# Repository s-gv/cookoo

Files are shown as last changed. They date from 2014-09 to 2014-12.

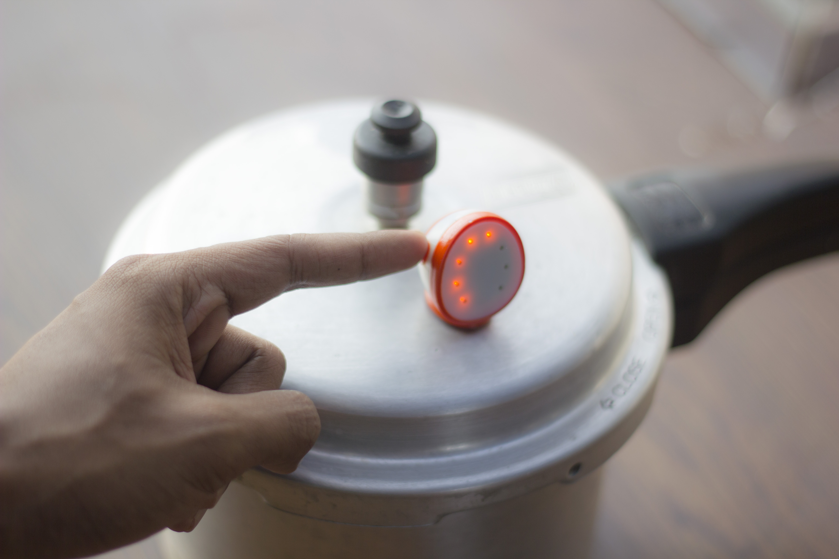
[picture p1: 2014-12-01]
images/_MG_3987.jpg

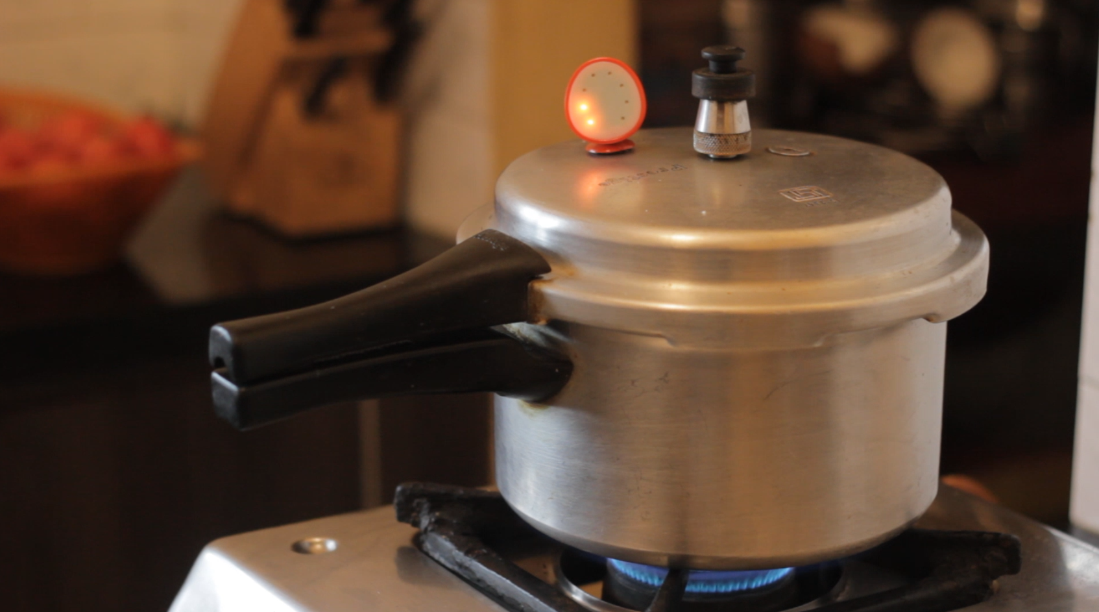
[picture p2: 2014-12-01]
images/whistle1.png

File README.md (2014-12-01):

cookoo
======

Cookoo is a pressure cooker whistle counter. Keep it on your cooker and forget about it. Cookoo will tell you when to turn off the stove.

Dependencies
------------

- MSPGCC and GNU Make (only if you want to re-build)
- Flash Programmer (TI Launchpad will do)
- Flash Programmer Tool (TI Code Composer Studio / FET-Pro430 / TI MSP430 Flasher/ mspdebug)

On Ubuntu 12.04, the dependencies can be installed with `sudo apt-get install binutils-msp430 gcc-msp430 msp430-libc mspdebug`

How-to-use
----------

- Build the circuit in the [schematic](schematic/whistle_counter.png) and program the MSP430 with the [hex file](bin/msp430cookoo.hex)
- [Gerber files](pcb/gerber) for the PCB are available along with images to [assist manual assembly](pcb/)
- The [STL files](enclosure/) may be used to 3D-print an enclosure

Notes
-----

- Pour hot glue over the crystal pins, the 22pF caps, and all over the MSP430 pins to prevent moisture from interfering with the low-power 32kHz crystal oscillator
- The [PCB design](pcb/) included has a minor inconvenience. For the wire-terminated thermistor, SMD0402 pads have been provided (rather than two through-holes)
- The contact area with the cooker should be at least 1cm x 1cm for efficient heat transfer. To do this, paste the thermistor on the backside of a thin copper sheet.

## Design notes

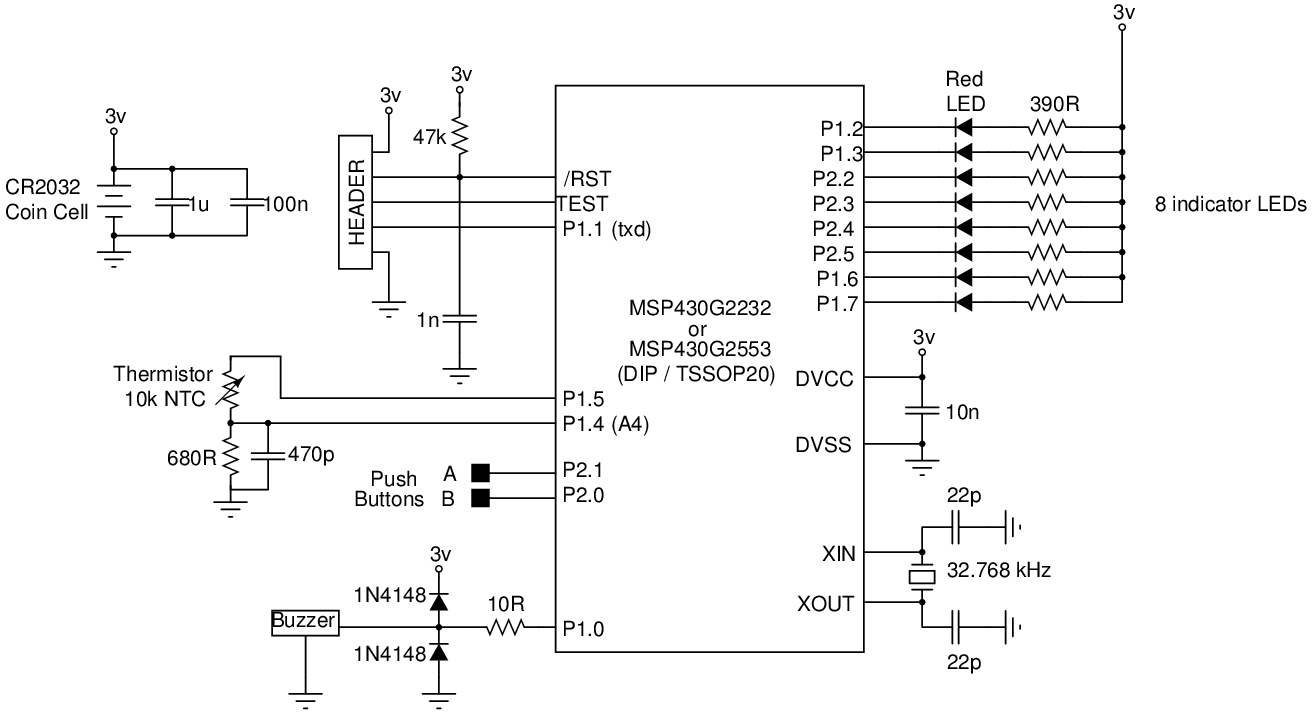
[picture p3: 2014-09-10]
schematic/whistle_counter.png

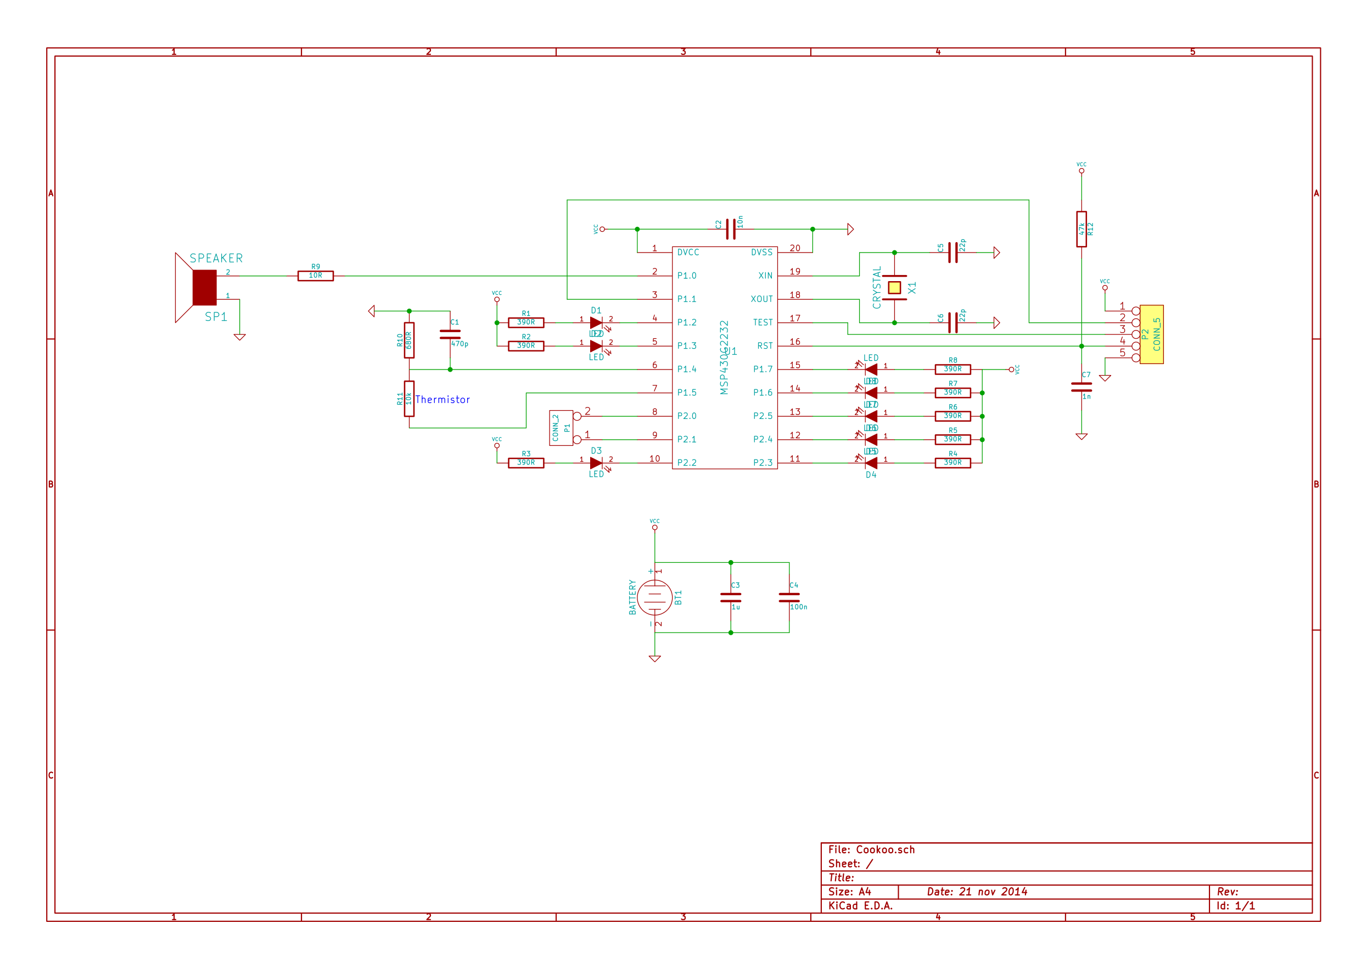
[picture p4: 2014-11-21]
pcb/pcb_schematic.png

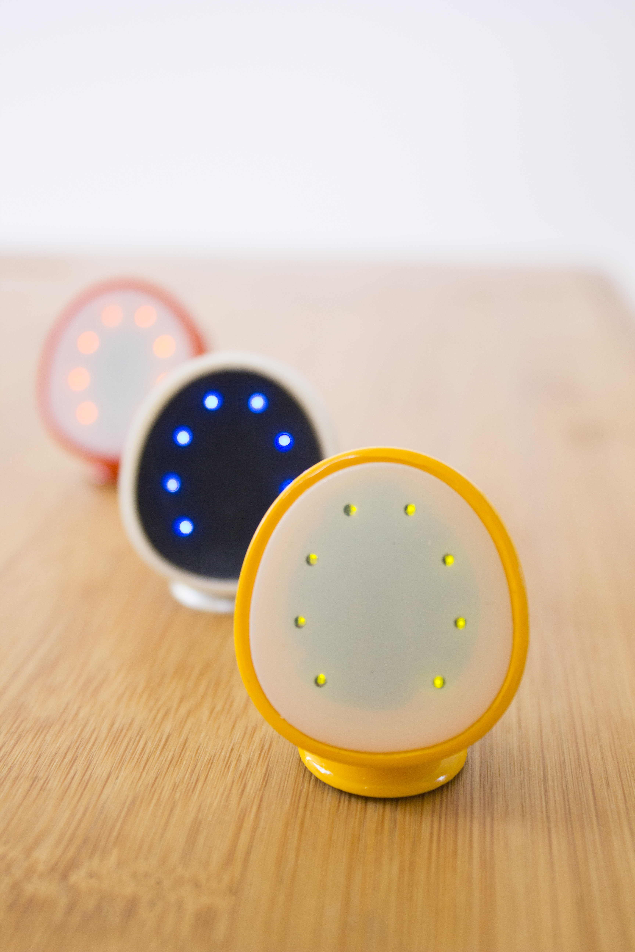
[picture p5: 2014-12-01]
images/_MG_3925.jpg

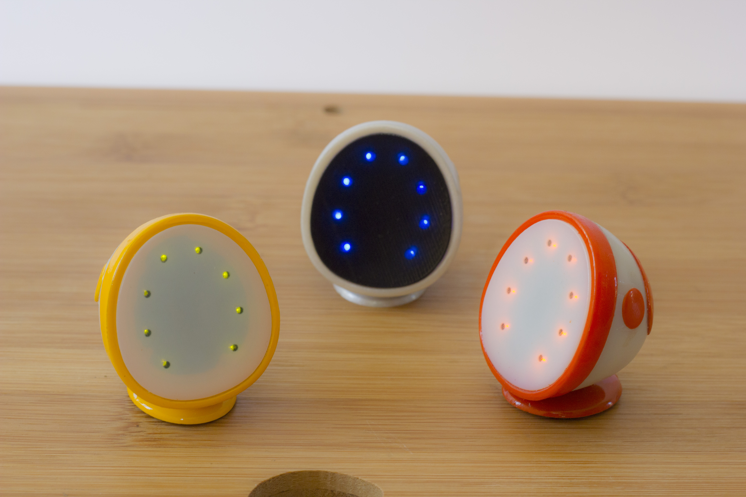
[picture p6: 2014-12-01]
images/_MG_3888.jpg

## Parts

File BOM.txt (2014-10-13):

Quantity x Part Number
======================

1x MSP430G2232 (TSSOP 20 pin)

1x CR2032 Coin cell battery and battery holder

1x Buzzer (through hole, continuous > 80 dB indicator buzzer)

1x 32.768 kHz Crystal (through hole)

2x 1N4148 diode (through hole)

8x Red LED (SMD 0402)

1x 10k 1/16 W NTC Thermistor (Wire terminated, Upto 150 degree Celcius)

1x 10R, 1/16 W (SMD 0402)
8x 390R, 1/16 W (SMD 0402)
1x 680R, 1/16 W (SMD 0402)
1x 47k, 1/16 W (SMD 0402)

2x 22pF, 5V (SMD 0402, Ceramic)
1x 470pF, 5V (SMD 0402, Ceramic)
1x 1nF, 5V (SMD 0402, Ceramic)
1x 10nF, 5V (SMD 0402, Ceramic)
1x 100nF, 5V (SMD 0402, Ceramic)
1x 1uF, 5V (SMD 0402, Ceramic)

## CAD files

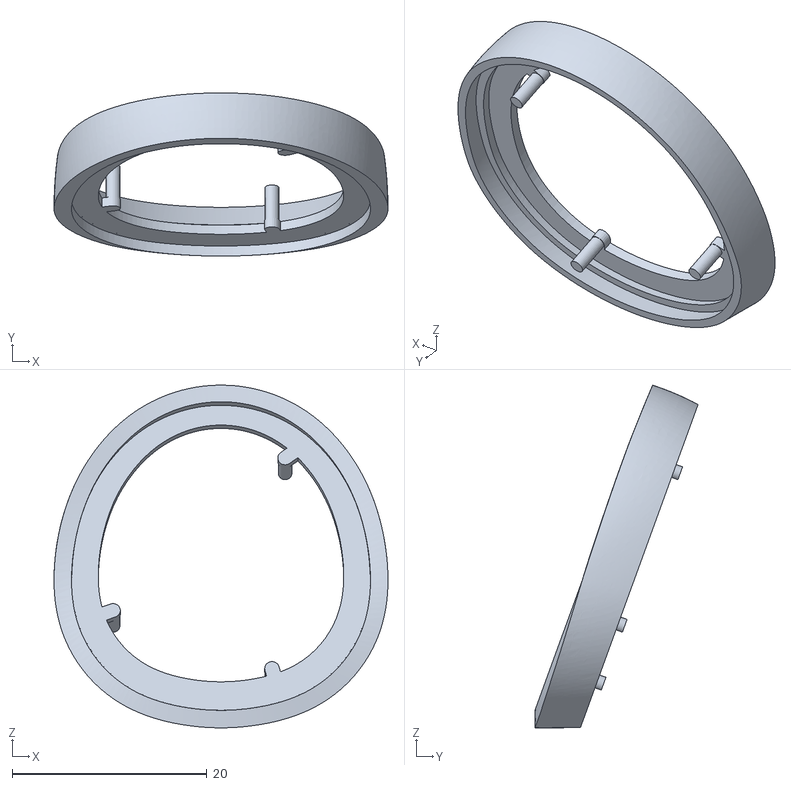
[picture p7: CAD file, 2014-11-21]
enclosure/Front.stl
34.3 x 16.8 x 35.2

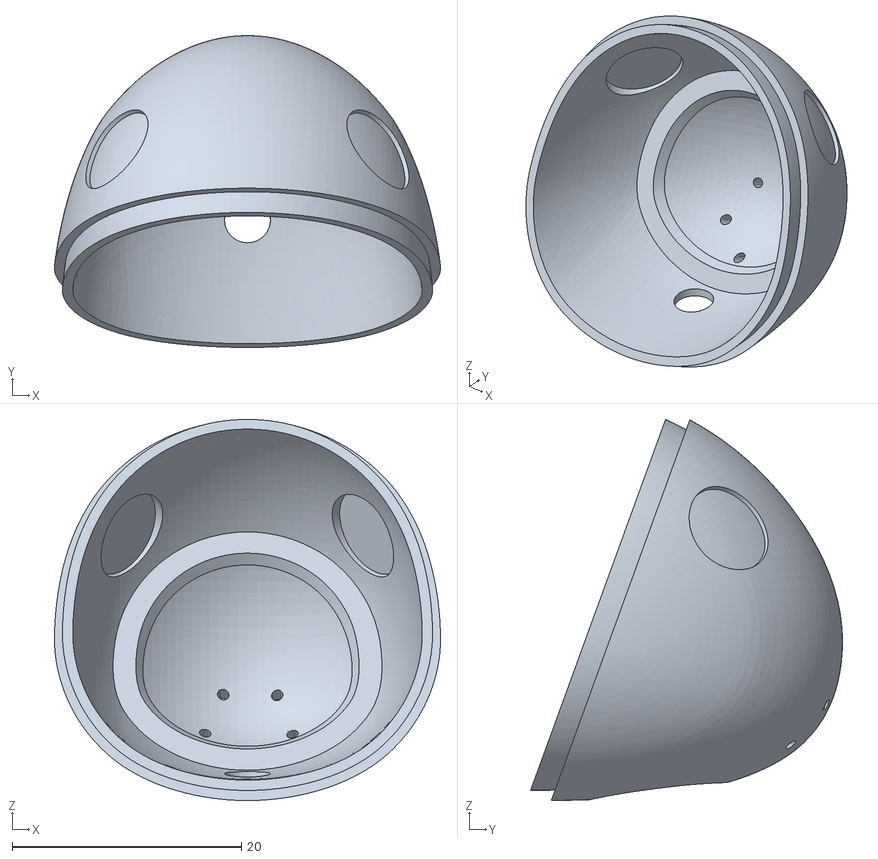
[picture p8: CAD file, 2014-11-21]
enclosure/Rear.stl
33.6 x 27.2 x 33.2

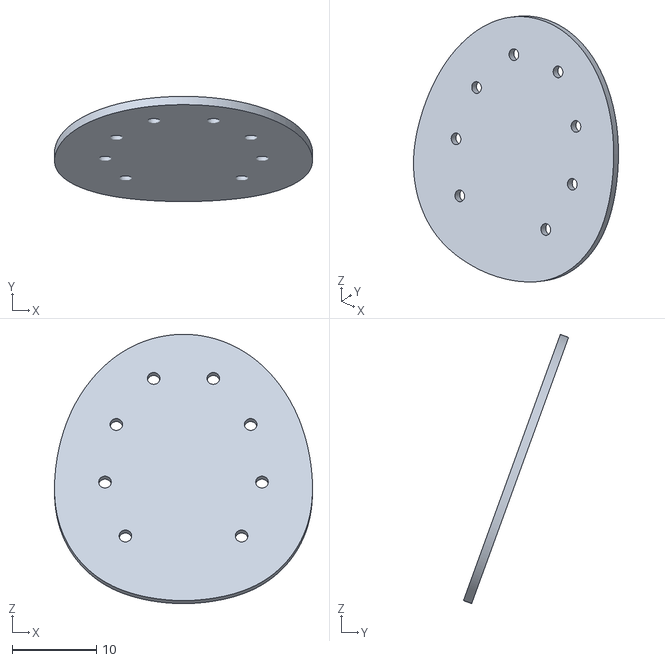
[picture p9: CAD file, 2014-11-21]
enclosure/Panel.stl
30.7 x 12.5 x 32.0

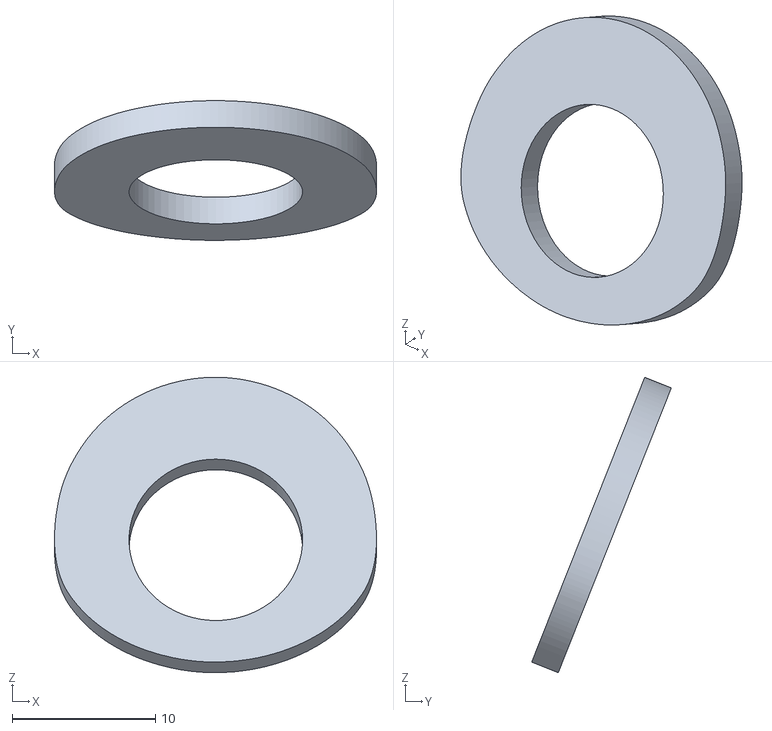
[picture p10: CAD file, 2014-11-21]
enclosure/buzzerPlate.stl
22.4 x 9.74 x 20.6

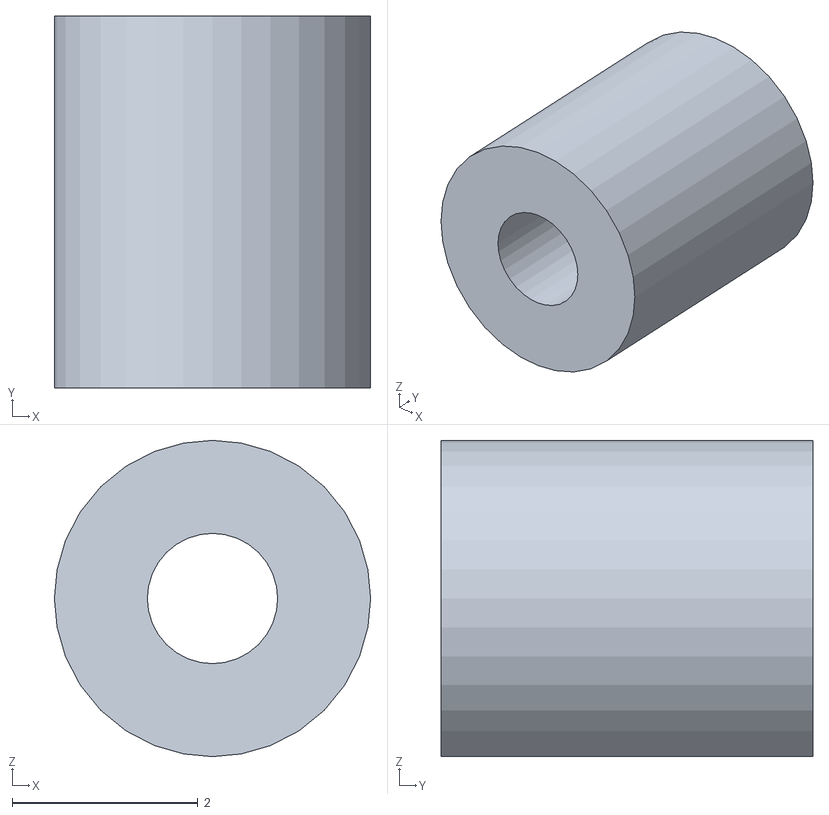
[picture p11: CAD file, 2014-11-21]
enclosure/Plug.stl
3.40 x 4.00 x 3.40

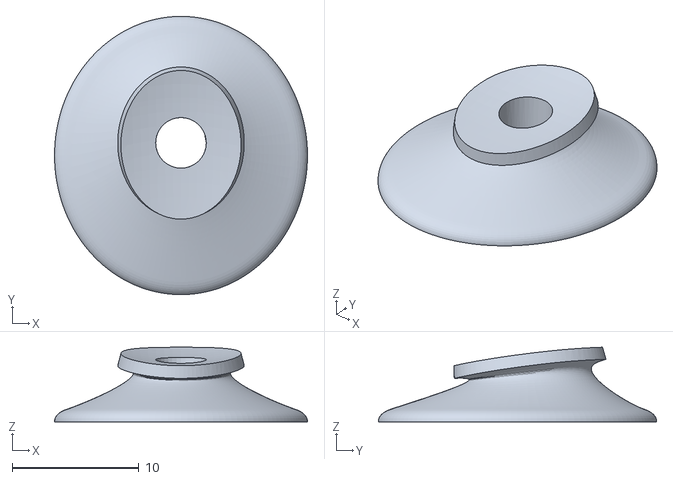
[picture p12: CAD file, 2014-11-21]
enclosure/stand.stl
20.0 x 22.0 x 5.90

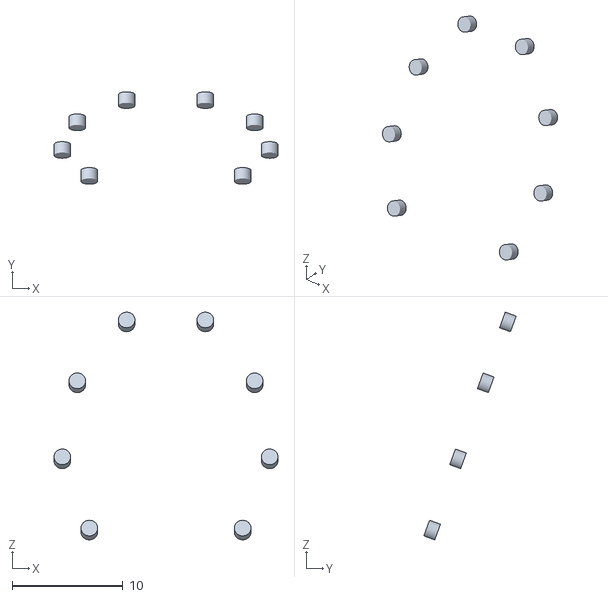
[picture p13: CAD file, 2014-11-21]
enclosure/leds.stl
20.2 x 8.33 x 20.5

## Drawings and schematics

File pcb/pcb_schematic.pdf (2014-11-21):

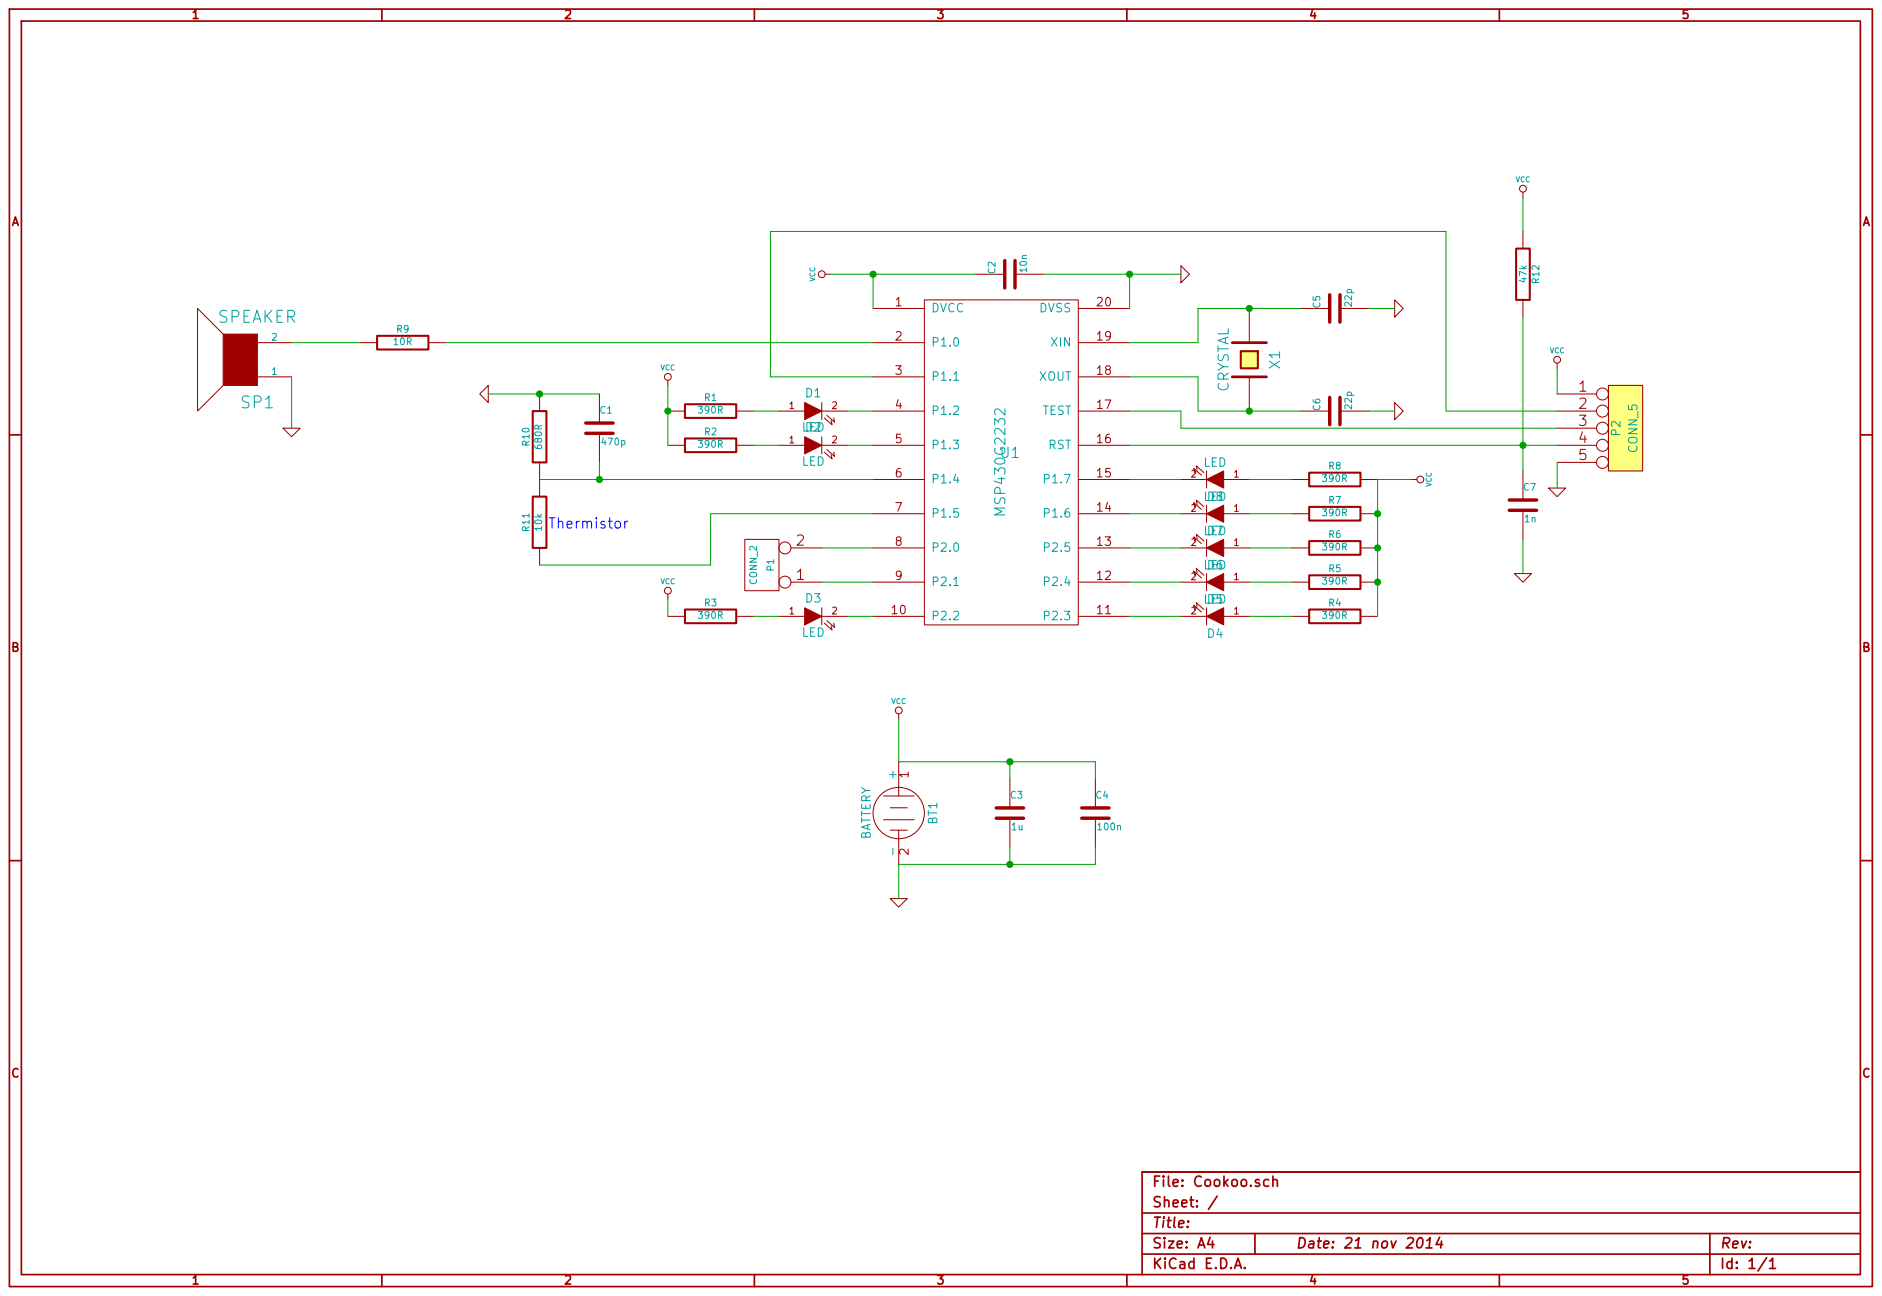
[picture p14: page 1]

-2 BT1 BATTERY DVCC 1 P1.0 2 P1.1 3 P1.2 4 P1.3 5 P1.4 6 P1.5 7 P2.0 8 P2.1 9 P2.2 10 DVSS 20 P2.3 11 P2.4 12 P2.5 13 P1.6 14 P1.7 15 RST 16 TEST 17 XOUT 18 XIN 19 U1MSP430G2232 C522p C622p

Id: 1/1 Title: File: Cookoo.sch

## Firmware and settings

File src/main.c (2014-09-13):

/*
Copyright (c) 2014, Sagar G V (sagar.writeme@gmail.com) and Dhruv Saxena (dhruvrai23@gmail.com)
All rights reserved.

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
* Neither the names of the copyright holders nor the names of its
  contributors may be used to endorse or promote products derived from
  this software without specific prior written permission.

THIS SOFTWARE IS PROVIDED BY THE COPYRIGHT HOLDERS AND CONTRIBUTORS "AS IS"
AND ANY EXPRESS OR IMPLIED WARRANTIES, INCLUDING, BUT NOT LIMITED TO, THE
IMPLIED WARRANTIES OF MERCHANTABILITY AND FITNESS FOR A PARTICULAR PURPOSE ARE
DISCLAIMED. IN NO EVENT SHALL THE COPYRIGHT HOLDER OR CONTRIBUTORS BE LIABLE
FOR ANY DIRECT, INDIRECT, INCIDENTAL, SPECIAL, EXEMPLARY, OR CONSEQUENTIAL
DAMAGES (INCLUDING, BUT NOT LIMITED TO, PROCUREMENT OF SUBSTITUTE GOODS OR
SERVICES; LOSS OF USE, DATA, OR PROFITS; OR BUSINESS INTERRUPTION) HOWEVER
CAUSED AND ON ANY THEORY OF LIABILITY, WHETHER IN CONTRACT, STRICT LIABILITY,
OR TORT (INCLUDING NEGLIGENCE OR OTHERWISE) ARISING IN ANY WAY OUT OF THE USE
OF THIS SOFTWARE, EVEN IF ADVISED OF THE POSSIBILITY OF SUCH DAMAGE.
*/

#include <msp430.h>
#include <inttypes.h>

#include "cappush.h"
#include "cookoo.h"
#include "uart.h"
#include "hal.h"

int main(void) {
    uint16_t tempSensor, battery;
    uint8_t capPushA, capPushB;
    uint8_t it=1;

    InitWDT();
    InitCLOCK();
    InitUART();
    InitLED();
    InitADC();
    InitBuzzer();
    InitCapPush();
    
    EnableInterrupts();
    while (1) {
        it--;
        if(it == 0) {
            it = 4;
            capPushA = senseCapPushA(); 
            capPushB = senseCapPushB(); 
            tempSensor = ReadTemp();
            battery = ReadBattery(); 
            MainLoop(capPushA, capPushB, tempSensor, battery);
        }
        SetupWDTToWakeUpCPU(2); // Wake up in 16 mS
        Sleep();
    }
    return 0;
}

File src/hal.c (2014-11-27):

/*
Copyright (c) 2014, Sagar G V (sagar.writeme@gmail.com) and Dhruv Saxena (dhruvrai23@gmail.com)
All rights reserved.

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
* Neither the names of the copyright holders nor the names of its
  contributors may be used to endorse or promote products derived from
  this software without specific prior written permission.

THIS SOFTWARE IS PROVIDED BY THE COPYRIGHT HOLDERS AND CONTRIBUTORS "AS IS"
AND ANY EXPRESS OR IMPLIED WARRANTIES, INCLUDING, BUT NOT LIMITED TO, THE
IMPLIED WARRANTIES OF MERCHANTABILITY AND FITNESS FOR A PARTICULAR PURPOSE ARE
DISCLAIMED. IN NO EVENT SHALL THE COPYRIGHT HOLDER OR CONTRIBUTORS BE LIABLE
FOR ANY DIRECT, INDIRECT, INCIDENTAL, SPECIAL, EXEMPLARY, OR CONSEQUENTIAL
DAMAGES (INCLUDING, BUT NOT LIMITED TO, PROCUREMENT OF SUBSTITUTE GOODS OR
SERVICES; LOSS OF USE, DATA, OR PROFITS; OR BUSINESS INTERRUPTION) HOWEVER
CAUSED AND ON ANY THEORY OF LIABILITY, WHETHER IN CONTRACT, STRICT LIABILITY,
OR TORT (INCLUDING NEGLIGENCE OR OTHERWISE) ARISING IN ANY WAY OUT OF THE USE
OF THIS SOFTWARE, EVEN IF ADVISED OF THE POSSIBILITY OF SUCH DAMAGE.
*/

#include "hal.h"

static void __attribute__((__interrupt__(WDT_VECTOR))) WDT_ISR(void) {
    LPM3_EXIT; // Return to active mode
}

static void __attribute__((__interrupt__(ADC10_VECTOR))) ADC10_ISR(void) {
    LPM3_EXIT; // Return to active mode
}


/*
// If you're using TI's Code Composer for MSP430, replace the above two ISRs with the following.

#pragma vector=WDT_VECTOR,ADC10_VECTOR
__interrupt void ISR(void) {
    LPM3_EXIT; // Return to active mode
}
*/

////////////////////////////////////////////////////////////////////////////////////////////////////////
void InitBuzzer() {
    P1DIR |= 1 << 0;
    P1OUT &= ~(1 << 0);
}
void InitWDT() {
    WDTCTL = WDTPW | WDTHOLD;
    IE1 |= WDTIE;
}
void InitUART() {
    P1DIR |= (1 << 1);
    P1OUT |= (1 << 1);
}

void InitCLOCK() {
    BCSCTL3 |= XCAP_3; // Set ACLK to 32 kHZ crystal
    BCSCTL1 = CALBC1_1MHZ; // Set DCO to 1MHz
    DCOCTL = CALDCO_1MHZ; // Set DCO to 1MHz
}

void InitLED() {
    // P1.2 is led 0, P1.3 is led 1
    // P2.2 is led 2, P2.3 is led 3, P2.4 is led 4, P2.5 is led 5
    // P1.6 is led 6, P1.7 is led 7
    P2DIR |= (1 << 5) | (1 << 4) | (1 << 3) | (1 << 2);
    P1DIR |= (1 << 7) | (1 << 6) | (1 << 3) | (1 << 2);

    // Turn off the LEDs
    AllLEDOff();
}

void InitCapPush() {
    P2DIR |= (1 << 1) | (1 << 0); // P2.0 and P2.1 are cap touch pins
}

void InitADC() {
    ADC10AE0 |= BIT4; //ADC Input pin P1.4
    P1DIR |= (1 << 5); // P1.5 is connected to upper side of resistor divider
    P1OUT &= ~(1 << 5); // Turn off power to the resistor divider
}

void EnableInterrupts() {
    __enable_interrupt();
}

////////////////////////////////////////////////////////////////////////////////////////////////////////

void UARTsb(uint8_t val) {
    // This works at 2400 baud, 1 MHz CPU
#define UART_BIT_CYCLES 415
#define UART_SEND_ZERO P1OUT &= ~(1 << 1);
#define UART_SEND_ONE P1OUT |= (1 << 1);

    // Send 0 (start bit)
    UART_SEND_ZERO
    ;
    __delay_cycles(UART_BIT_CYCLES);

    /*
     UART_SEND_ONE;
     __delay_cycles(UART_BIT_CYCLES);
     UART_SEND_ZERO;
     __delay_cycles(UART_BIT_CYCLES);
     UART_SEND_ZERO;
     __delay_cycles(UART_BIT_CYCLES);
     UART_SEND_ZERO;
     __delay_cycles(UART_BIT_CYCLES);

     UART_SEND_ZERO;
     __delay_cycles(UART_BIT_CYCLES);
     UART_SEND_ZERO;
     __delay_cycles(UART_BIT_CYCLES);
     UART_SEND_ONE;
     __delay_cycles(UART_BIT_CYCLES);
     UART_SEND_ZERO;
     __delay_cycles(UART_BIT_CYCLES);
     */

    // Send Bit 0 (lsb)
    if (val & 0x01) {
        UART_SEND_ONE
        ;
    } else {
        UART_SEND_ZERO
        ;
    }
    __delay_cycles(UART_BIT_CYCLES);

    // Send Bit 1
    if (val & 0x02) {
        UART_SEND_ONE
        ;
    } else {
        UART_SEND_ZERO
        ;
    }
    __delay_cycles(UART_BIT_CYCLES);

    // Send Bit 2
    if (val & 0x04) {
        UART_SEND_ONE
        ;
    } else {
        UART_SEND_ZERO
        ;
    }
    __delay_cycles(UART_BIT_CYCLES);

    // Send Bit 3
    if (val & 0x08) {
        UART_SEND_ONE
        ;
    } else {
        UART_SEND_ZERO
        ;
    }
    __delay_cycles(UART_BIT_CYCLES);

    // Send Bit 4
    if (val & 0x10) {
        UART_SEND_ONE
        ;
    } else {
        UART_SEND_ZERO
        ;
    }
    __delay_cycles(UART_BIT_CYCLES);

    // Send Bit 5
    if (val & 0x20) {
        UART_SEND_ONE
        ;
    } else {
        UART_SEND_ZERO
        ;
    }
    __delay_cycles(UART_BIT_CYCLES);

    // Send Bit 6
    if (val & 0x40) {
        UART_SEND_ONE
        ;
    } else {
        UART_SEND_ZERO
        ;
    }
    __delay_cycles(UART_BIT_CYCLES);

    // Send Bit 7 (msb)
    if (val & 0x80) {
        UART_SEND_ONE
        ;
    } else {
        UART_SEND_ZERO
        ;
    }
    __delay_cycles(UART_BIT_CYCLES);

    // Send 1 (stop bits)
    UART_SEND_ONE
    ;
    /*
     uint8_t i;
     for (i = 0; i < 20; i++)
     __delay_cycles(UART_BIT_CYCLES);
     */

}

void Sleep() {
    LPM3; // Goto sleep
}

void LEDOn(uint8_t led) {
    switch (led) {
    case 0:
        P1OUT &= ~(1 << 2);
        break;
    case 1:
        P1OUT &= ~(1 << 3);
        break;
    case 2:
        P2OUT &= ~(1 << 2);
        break;
    case 3:
        P2OUT &= ~(1 << 3);
        break;
    case 4:
        P2OUT &= ~(1 << 4);
        break;
    case 5:
        P2OUT &= ~(1 << 5);
        break;
    case 6:
        P1OUT &= ~(1 << 6);
        break;
    case 7:
        P1OUT &= ~(1 << 7);
        break;
    default:
        break;
    }
}
void LEDOff(uint8_t led) {
    switch (led) {
    case 0:
        P1OUT |= (1 << 2);
        break;
    case 1:
        P1OUT |= (1 << 3);
        break;
    case 2:
        P2OUT |= (1 << 2);
        break;
    case 3:
        P2OUT |= (1 << 3);
        break;
    case 4:
        P2OUT |= (1 << 4);
        break;
    case 5:
        P2OUT |= (1 << 5);
        break;
    case 6:
        P1OUT |= (1 << 6);
        break;
    case 7:
        P1OUT |= (1 << 7);
        break;
    default:
        break;
    }
}
void LEDToggle(uint8_t led) {
    switch (led) {
    case 0:
        P1OUT ^= (1 << 2);
        break;
    case 1:
        P1OUT ^= (1 << 3);
        break;
    case 2:
        P2OUT ^= (1 << 2);
        break;
    case 3:
        P2OUT ^= (1 << 3);
        break;
    case 4:
        P2OUT ^= (1 << 4);
        break;
    case 5:
        P2OUT ^= (1 << 5);
        break;
    case 6:
        P1OUT ^= (1 << 6);
        break;
    case 7:
        P1OUT ^= (1 << 7);
        break;
    default:
        break;
    }
}

void AllLEDOn() {
    uint8_t i;
    for (i = 0; i < 8; i++)
        LEDOn(i);
}
void AllLEDOff() {
    uint8_t i;
    for (i = 0; i < 8; i++)
        LEDOff(i);
}
void AllLEDToggle() {
    uint8_t i;
    for (i = 0; i < 8; i++)
        LEDToggle(i);
}

void SetupWDTToWakeUpCPU(uint8_t clkdiv) {
    WDTCTL = WDTPW | WDTTMSEL | WDTCNTCL | WDTSSEL | clkdiv;
}
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

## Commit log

2014-09-06 Tested on pressure cooker
2014-09-06 Tentative BOM
2014-09-06 Wiring to use TI launchpad as MSP430 flash programmer
2014-09-10 changed to lower case
2014-09-10 Over temp. and low battery warning
2014-09-13 Some basic power measurements
2014-09-13 Fixed power issue with cap touch sensors
    [hal.c, main.c]
2014-09-13 Fixed power consumption issue with temp. sensor using ADC
    [hal.c, main.c]
2014-09-13 Fixed power issue with band-gap reference
    [hal.c, main.c]
2014-09-13 With all untested power enhancements
2014-09-13 Power numbers for ADC
2014-09-14 Removed unused UART functions
2014-09-15 Disabling down-sampling on both buttons when a push is detected
2014-09-15 The mac mspgcc seems to give slightly lower power
2014-10-30 Fixed LED change being interpreted as cap push
2014-11-02 Fixed temperature threshold
2014-11-20 Cookoo PCB gerbers
    [CookooFinal-append-B_Cu.gbl, CookooFinal-append-B_Mask.gbs, CookooFinal-append-B_SilkS.gbo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]
2014-11-21 pictures to assist manual PCB assembly
    [CookooFinal-append-B_Cu.gbl, CookooFinal-append-B_Mask.gbs, CookooFinal-append-B_SilkS.gbo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]
2014-11-21 STL files of 3D printer enclosure
    [Front.stl, Panel.stl, Plug.stl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]
2014-11-21 Notes on PCB and enclosure
2014-11-22 Note on Copper sheet for the thermistor
